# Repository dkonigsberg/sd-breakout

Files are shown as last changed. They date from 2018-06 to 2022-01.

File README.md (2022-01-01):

# microSD Breakout Board

This repository contains the [KiCad](https://www.kicad.org/) project
with the complete circuit schematics and PCB layout for a microSD
card breakout board. This board includes all the necessary pull-up
resistors and protection diodes for the full SD interface, courtesy
of the EClamp2410P component.

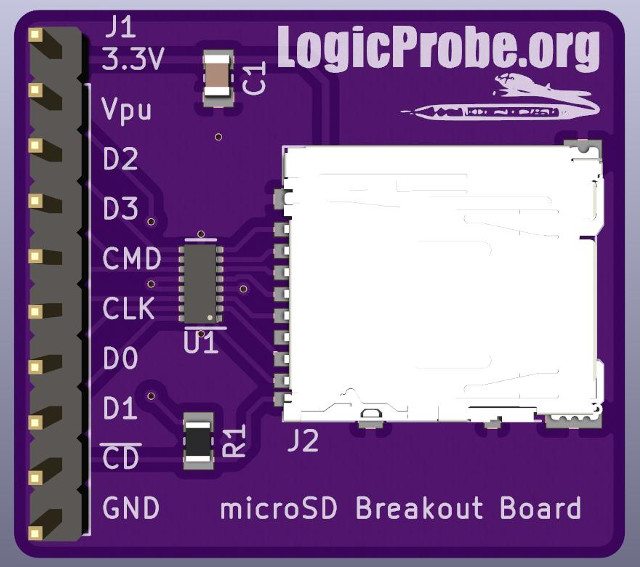
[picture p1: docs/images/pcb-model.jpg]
Board


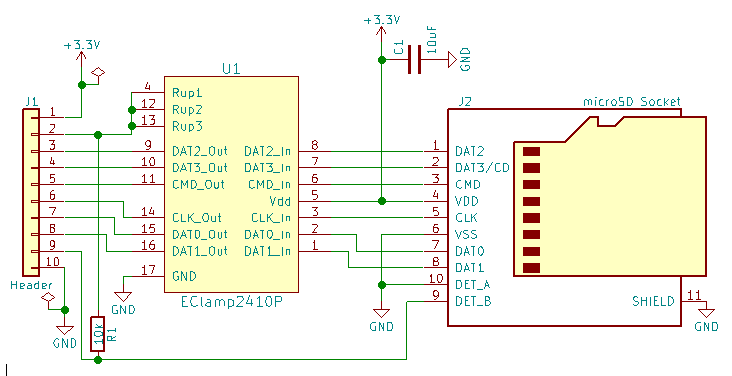
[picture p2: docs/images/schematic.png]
Schematic


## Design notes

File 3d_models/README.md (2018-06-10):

# 3D Component Models

## Introduction

The 3D models used by the components in these schematics come from a variety
of sources. Some were created for this project, using KiCad's library
scripts and/or FreeCAD directly. Many others were downloaded from component
manufacturer websites.

Some manufacturers have a habit of freely distributing 3D models for their
components with attached notes saying that they shall not be redistributed.
These notes also often mention that the models are proprietary, confidential,
for personal use only, or something else that would scare you off from
actually admitting that you used them. As such, these models have not been
included in the project repository. Instead, link for downloading them
is provided.

The actual conversion of component models to WRL files is accomplished
with the [KiCad StepUp plugin](https://sourceforge.net/projects/kicadstepup/).

## Model List

The models are listed by base filename. Typical distribution files have
the ".step" extension, while the exported files have the ".wrl" extension.

To include models marked as not redistributable, download them from the
original source and convert using the KiCad StepUp plugin for FreeCAD.
Make sure the original and converted files have the same base name as
listed below.

### DM3AT-SF-PEJM5
* Status: Not included (Not redistributable)
* Source: https://www.hirose.com/product/en/download_file/key_name/DM3AT-SF-PEJM5/category/Drawing%20(3D)(STEP)/doc_file_id/158358/?item_id=06090031000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

### SLP4016P16_1.6x4mm_P0.5mm
* Status: Included (Same license as project)
* Source: Created for project using modified KiCad model scripts

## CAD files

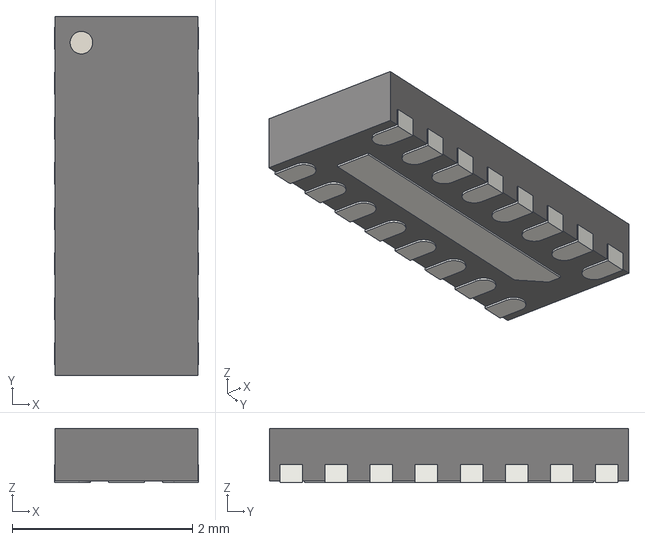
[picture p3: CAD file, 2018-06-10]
3d_models/SLP4016P16_1.6x4mm_P0.5mm.step
1.60 x 3.98 x 0.6 mm

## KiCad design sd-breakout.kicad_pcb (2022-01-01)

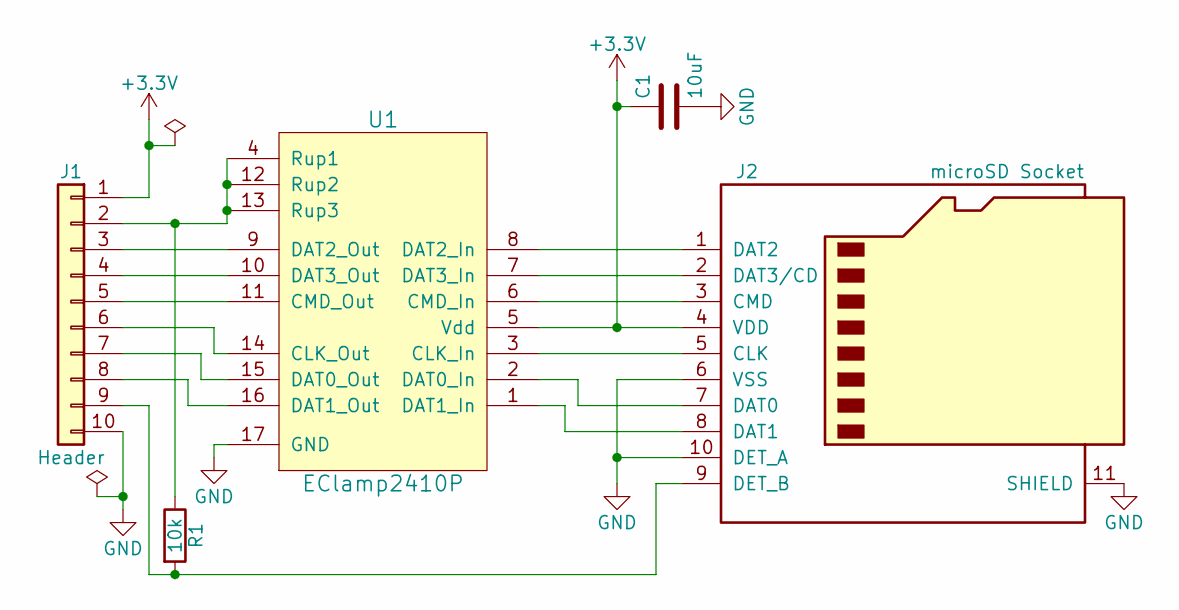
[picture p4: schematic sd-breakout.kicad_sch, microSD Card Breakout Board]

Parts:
C1: 10uF; C_0805_2012Metric; Manufacturer PN CL21A106KAFN3NE
J1: Header; PinHeader_1x10_P2.54mm_Vertical
J2: microSD Socket; microSD_HC_Hirose_DM3AT-SF-PEJM5; Manufacturer PN DM3AT-SF-PEJM5
R1: 10k; R_0805_2012Metric; Manufacturer PN CRCW080510K0JNEA
U1: EClamp2410P; SLP4016P16_1.6x4mm_P0.5mm; Manufacturer PN ECLAMP2410P.TCT

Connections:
+3V3: C1.1, J1.1, J2.4 (VDD), U1.5 (Vdd)
GND: C1.2, J1.10, J2.6 (VSS), J2.10 (DET_A), J2.11 (SHIELD), U1.17 (GND)
unnamed: J1.2, R1.1, U1.4 (Rup1), U1.12 (Rup2), U1.13 (Rup3)
unnamed: J1.3, U1.9 (DAT2_Out)
unnamed: J1.4, U1.10 (DAT3_Out)
unnamed: J1.5, U1.11 (CMD_Out)
unnamed: J1.6, U1.14 (CLK_Out)
unnamed: J1.7, U1.15 (DAT0_Out)
unnamed: J1.8, U1.16 (DAT1_Out)
unnamed: J1.9, J2.9 (DET_B), R1.2
unnamed: J2.1 (DAT2), U1.8 (DAT2_In)
unnamed: J2.2 (DAT3/CD), U1.7 (DAT3_In)
unnamed: J2.3 (CMD), U1.6 (CMD_In)
unnamed: J2.5 (CLK), U1.3 (CLK_In)
unnamed: J2.7 (DAT0), U1.2 (DAT0_In)
unnamed: J2.8 (DAT1), U1.1 (DAT1_In)

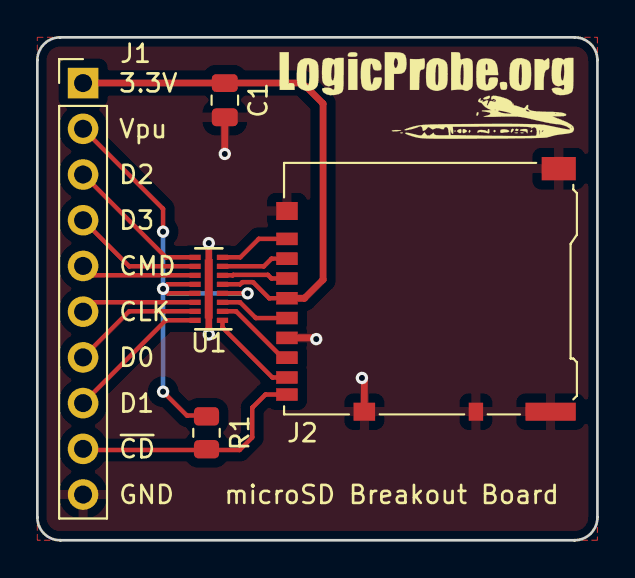
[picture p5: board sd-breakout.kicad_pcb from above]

Board: 2 copper layers, 31.1 x 27.9 mm, 5 parts (0 on the bottom side), 16 nets.

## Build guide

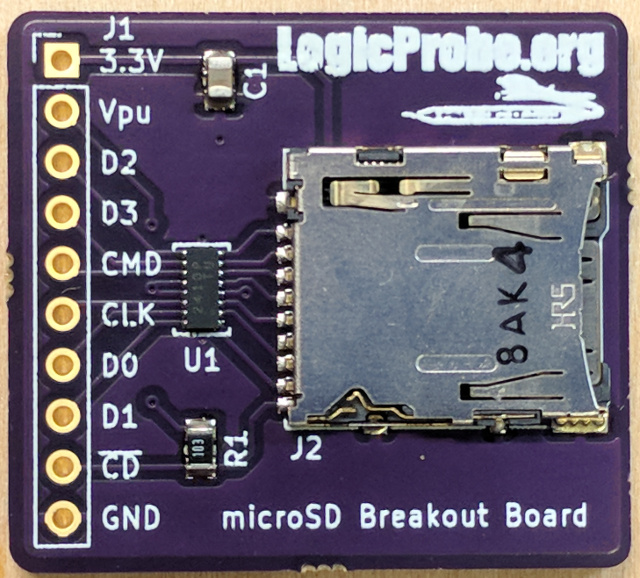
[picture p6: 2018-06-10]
docs/images/pcb-assembled.jpg

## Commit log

2018-03-06 Initial commit for standalone SD breakout board project
    [sd-breakout.kicad_pcb, sd-breakout.sch]
2018-03-06 Finished layout and added logos
    [sd-breakout.kicad_pcb, sd-breakout.sch]
2018-06-10 Added BOM tool configuration file
2018-06-10 Added photo of assembled board
2018-06-10 Add image of schematic
2018-06-10 Updated footprint and model for EClamp chip
    [SLP4016P16_1.6x4mm_P0.5mm.step]
2018-06-10 Component 3D model updates
    [sd-breakout.kicad_pcb]
2018-06-10 Add image of 3D PCB model
2022-01-01 Updated project to KiCad v6
    [sd-breakout.kicad_pcb, sd-breakout.kicad_sch, sd-breakout.sch]
2022-01-01 Fix KiCad project URL
